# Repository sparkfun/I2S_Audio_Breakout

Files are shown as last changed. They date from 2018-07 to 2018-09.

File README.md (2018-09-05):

SparkFun I2S Audio Breakout
========================================

I2S Audio Breakout

[*I2S Audio Breakout (DEV-14809)*](https://www.sparkfun.com/products/14809)

The I2S Audio Breakout board uses the MAX98357A digital to analog converter (DAC), which converts I2S (not be confused with I2C) audio to an analog signal to drive speakers. The MAX98357A has a built in class D amplifier which can deliver up to 3.2W of power into a 4Ω load. To use this board, all you need is a speaker and a microcontroller that supports I2S. I2S is currently supported on our [SAMD21 Dev Breakout](https://www.sparkfun.com/products/13672), [SAMD21 Mini](https://www.sparkfun.com/products/13664), [ESP8266 Thing](https://www.sparkfun.com/products/13231), and [ESP32 Thing](https://www.sparkfun.com/products/13907) boards.

Repository Contents
-------------------

* **/Hardware** - Eagle design files (.brd, .sch)
* **/Production** - Production panel files (.brd)

Documentation
--------------
* **[Hookup Guide](https://learn.sparkfun.com/tutorials/i2s-audio-breakout-hookup-guide)** - Basic hookup guide for the I2S Audio Breakout.

License Information
-------------------

This product is _**open source**_! 

Please review the LICENSE.md file for license information. 

If you have any questions or concerns on licensing, please contact techsupport@sparkfun.com.

Distributed as-is; no warranty is given.

- Your friends at SparkFun.

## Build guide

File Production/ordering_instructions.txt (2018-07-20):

panel size, 222x160mm
PCB thickness, 1.6mm
number of layers, 2
soldermask color, Red
silkscreen color, White
oz copper, 1oz
finish, HASL lead free
stencils, none
pcs per panel, 70

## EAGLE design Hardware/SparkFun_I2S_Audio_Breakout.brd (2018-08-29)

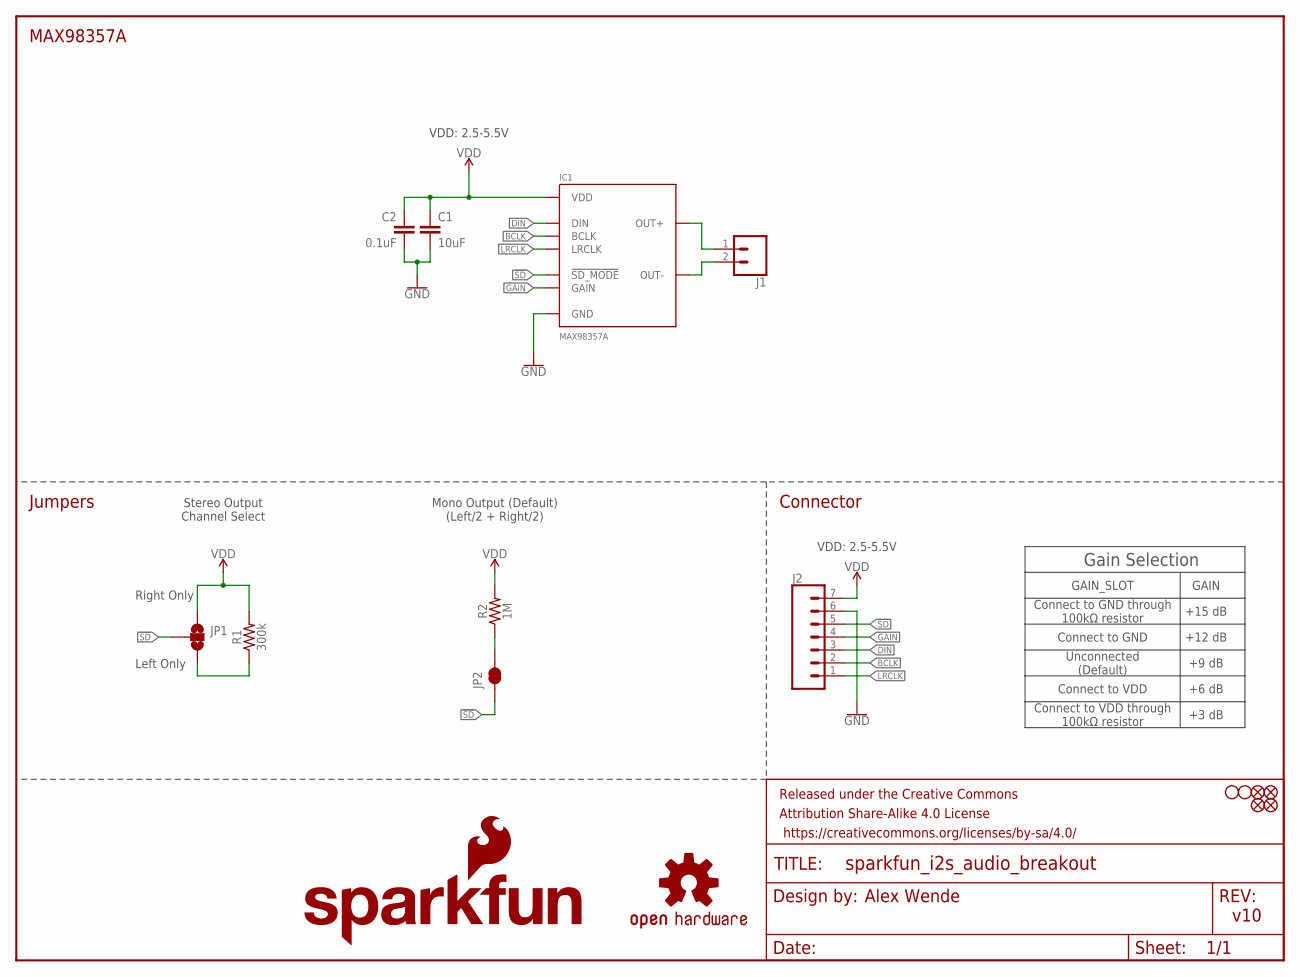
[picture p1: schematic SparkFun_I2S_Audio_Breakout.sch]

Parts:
C1: 10uF; 0805
C2: 0.1uF; 0603
FD1, FD2, FD3, FD4: FIDUCIALUFIDUCIAL; FIDUCIAL-MICRO
FRAME1: FRAME-LETTER; CREATIVE_COMMONS
H1, H2: STAND-OFF
IC1: MAX98357A; TQFN-16
J1: CONN_023.5MM-NO_SILK; SCREWTERMINAL-3.5MM-2-NS
J2: CONN_07NO_SILK; 1X07_NO_SILK
JP1: JUMPER-SMT_3_NO_NO-SILK; SMT-JUMPER_3_NO_NO-SILK
JP2: JUMPER-SMT_2_NC_TRACE_NO-SILK; SMT-JUMPER_2_NC_TRACE_NO-SILK
LOGO1: SFE_LOGO_NAME_FLAME.1_INCH; SFE_LOGO_NAME_FLAME_.1
LOGO2: OSHW-LOGOS; OSHW-LOGO-S
R1: 300k; 0603
R2: 1M; 0603

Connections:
!SD: IC1.P$4 (!SD_MODE), J2.5, JP1.2, JP2.1
BCLK: IC1.P$16 (BCLK), J2.2
DIN: IC1.P$1 (DIN), J2.3
GAIN: IC1.P$2 (GAIN), J2.4
GND: C1.2, C2.2, IC1.P$3 (GND), IC1.P$11 (GND), IC1.P$15 (GND), IC1.P$EP (GND), J2.6
LRCLK: IC1.P$14 (LRCLK), J2.1
unnamed: JP2.2, R2.1
unnamed: JP1.3, R1.1
OUT+: IC1.P$9 (OUT+), J1.1
OUT-: IC1.P$10 (OUT-), J1.2
VDD: C1.1, C2.1, IC1.P$7 (VDD), IC1.P$8 (VDD), J2.7, JP1.1, R1.2, R2.2

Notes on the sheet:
Alex Wende
v10
MAX98357A
Connector
Jumpers
Left Only
Right Only
Mono Output (Default) (Left/2 + Right/2)
Stereo Output Channel Select
Gain Selection
Connect to GND through 100kΩ resistor
Connect to GND
Unconnected (Default)
Connect to VDD
Connect to VDD through 100kΩ resistor
+15 dB
+12 dB
+9 dB
+6 dB
+3 dB
GAIN_SLOT
GAIN
VDD: 2.5-5.5V

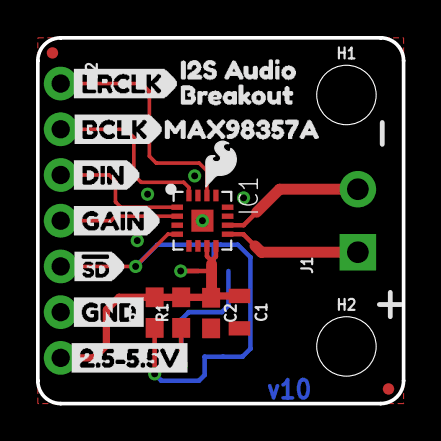
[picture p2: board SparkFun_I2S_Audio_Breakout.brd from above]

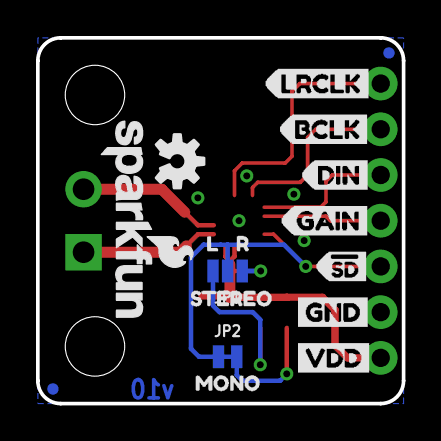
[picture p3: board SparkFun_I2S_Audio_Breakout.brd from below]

Board: 2 copper layers, 20.3 x 20.3 mm, 40 parts (17 on the bottom side), 11 nets.

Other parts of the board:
U$1: 2#5#5#5V13
U$2, U$23: GND9
U$3: #SD7
U$4: GAIN6
U$5: DIN5
U$6: BCLK4
U$7: LRCLK3
U$8: I2S_AUDIO0
U$9: BREAKOUT1
U$10: MAX98357A2
U$11: LRCLK0
U$12: BCLK1
U$13: DIN2
U$14: GAIN3
U$15: SFE_LOGO_FLAME_.1
U$16: MONO12
U$17: L10
U$18: R11
U$19: STEREO14
U$20: #SD4
U$22: VDD8

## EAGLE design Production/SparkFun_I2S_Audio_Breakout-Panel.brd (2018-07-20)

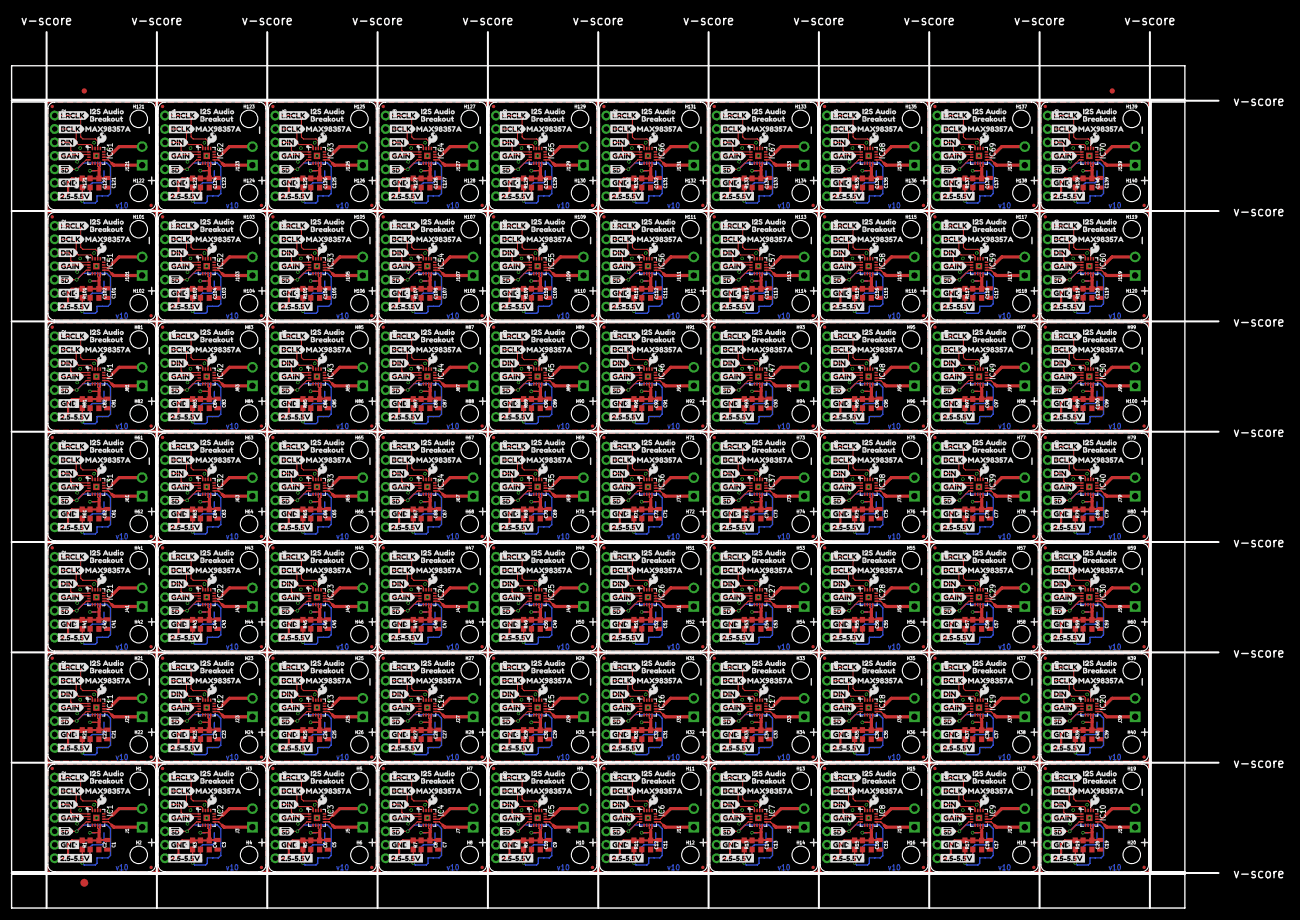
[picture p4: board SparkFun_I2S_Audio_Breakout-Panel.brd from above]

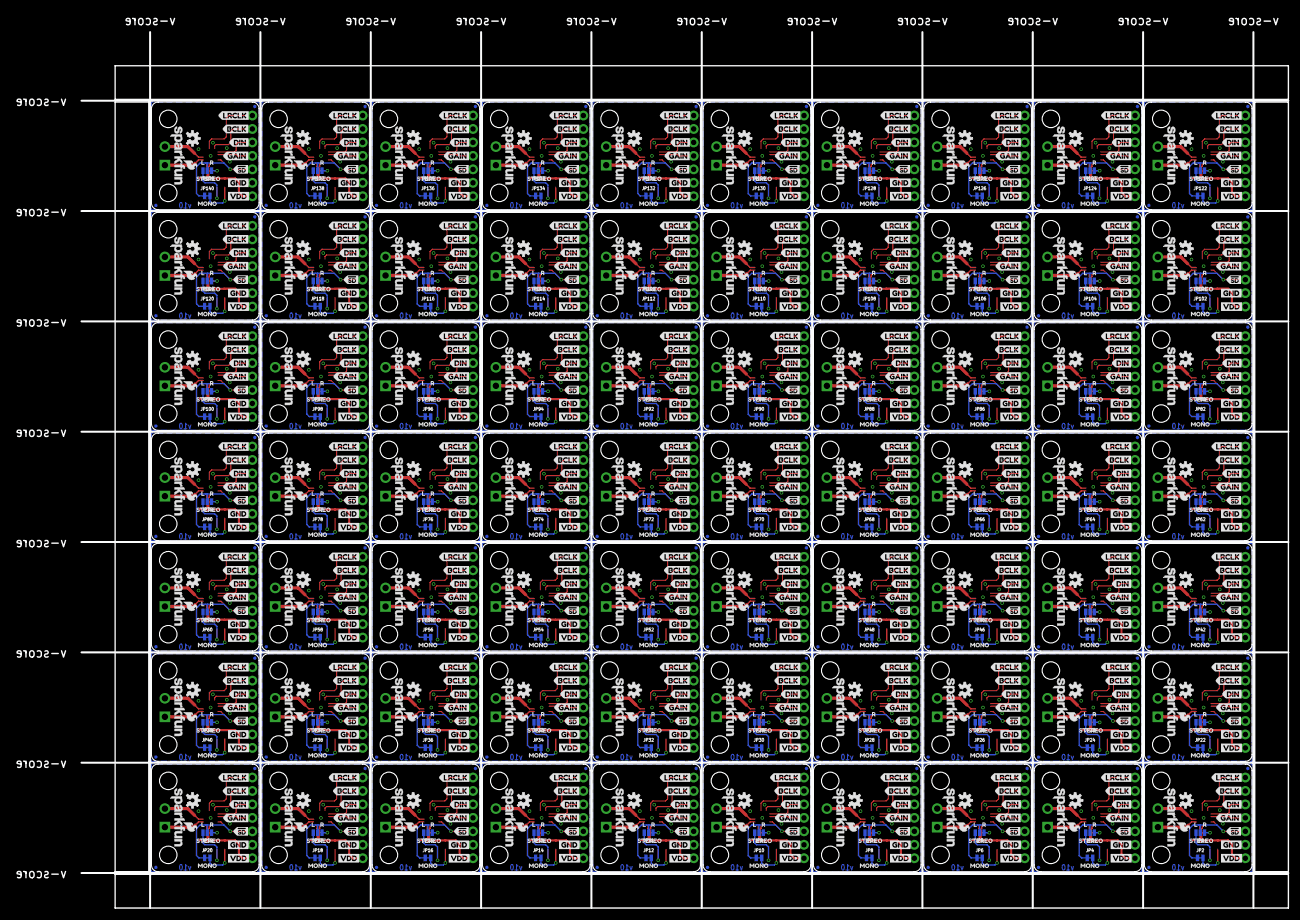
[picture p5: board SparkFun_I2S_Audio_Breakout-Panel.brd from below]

Board: 2 copper layers, 227.8 x 165.4 mm, 2733 parts (1190 on the bottom side), 770 nets.

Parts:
C1, C3, C5, C7, C9, C11, C13, C15, C17, C19, C21, C23, C25, C27, C29, C31, C33, C35, C37, C39, C41, C43, C45, C47, C49, C51, C53, C55, C57, C59, C61, C63, C65, C67, C69, C71, C73, C75, C77, C79, C81, C83, C85, C87, C89, C91, C93, C95, C97, C99, C101, C103, C105, C107, C109, C111, C113, C115, C117, C119, C121, C123, C125, C127, C129, C131, C133, C135, C137, C139: 10uF; 0805
C2, C4, C6, C8, C10, C12, C14, C16, C18, C20, C22, C24, C26, C28, C30, C32, C34, C36, C38, C40, C42, C44, C46, C48, C50, C52, C54, C56, C58, C60, C62, C64, C66, C68, C70, C72, C74, C76, C78, C80, C82, C84, C86, C88, C90, C92, C94, C96, C98, C100, C102, C104, C106, C108, C110, C112, C114, C116, C118, C120, C122, C124, C126, C128, C130, C132, C134, C136, C138, C140: 0.1uF; 0603
E$1, E$2: FIDUCIAL-1X2
E$3: FIDUCIAL-1.5X3
FD1, FD2, FD3, FD4, FD5, FD6, FD7, FD8, FD9, FD10, FD11, FD12, FD13, FD14, FD15, FD16, FD17, FD18, FD19, FD20, FD21, FD22, FD23, FD24, FD25, FD26, FD27, FD28, FD29, FD30, FD31, FD32, FD33, FD34, FD35, FD36, FD37, FD38, FD39, FD40, FD41, FD42, FD43, FD44, FD45, FD46, FD47, FD48, FD49, FD50, FD51, FD52, FD53, FD54, FD55, FD56, FD57, FD58, FD59, FD60, FD61, FD62, FD63, FD64, FD65, FD66, FD67, FD68, FD69, FD70, FD71, FD72, FD73, FD74, FD75, FD76, FD77, FD78, FD79, FD80, FD81, FD82, FD83, FD84, FD85, FD86, FD87, FD88, FD89, FD90, FD91, FD92, FD93, FD94, FD95, FD96, FD97, FD98, FD99, FD100, FD101, FD102, FD103, FD104, FD105, FD106, FD107, FD108, FD109, FD110, FD111, FD112, FD113, FD114, FD115, FD116, FD117, FD118, FD119, FD120, FD121, FD122, FD123, FD124, FD125, FD126, FD127, FD128, FD129, FD130, FD131, FD132, FD133, FD134, FD135, FD136, FD137, FD138, FD139, FD140, FD141, FD142, FD143, FD144, FD145, FD146, FD147, FD148, FD149, FD150, FD151, FD152, FD153, FD154, FD155, FD156, FD157, FD158, FD159, FD160, FD161, FD162, FD163, FD164, FD165, FD166, FD167, FD168, FD169, FD170, FD171, FD172, FD173, FD174, FD175, FD176, FD177, FD178, FD179, FD180, FD181, FD182, FD183, FD184, FD185, FD186, FD187, FD188, FD189, FD190, FD191, FD192, FD193, FD194, FD195, FD196, FD197, FD198, FD199, FD200, FD201, FD202, FD203, FD204, FD205, FD206, FD207, FD208, FD209, FD210, FD211, FD212, FD213, FD214, FD215, FD216, FD217, FD218, FD219, FD220, FD221, FD222, FD223, FD224, FD225, FD226, FD227, FD228, FD229, FD230, FD231, FD232, FD233, FD234, FD235, FD236, FD237, FD238, FD239, FD240, FD241, FD242, FD243, FD244, FD245, FD246, FD247, FD248, FD249, FD250, FD251, FD252, FD253, FD254, FD255, FD256, FD257, FD258, FD259, FD260, FD261, FD262, FD263, FD264, FD265, FD266, FD267, FD268, FD269, FD270, FD271, FD272, FD273, FD274, FD275, FD276, FD277, FD278, FD279, FD280: FIDUCIALUFIDUCIAL; FIDUCIAL-MICRO
H1, H2, H3, H4, H5, H6, H7, H8, H9, H10, H11, H12, H13, H14, H15, H16, H17, H18, H19, H20, H21, H22, H23, H24, H25, H26, H27, H28, H29, H30, H31, H32, H33, H34, H35, H36, H37, H38, H39, H40, H41, H42, H43, H44, H45, H46, H47, H48, H49, H50, H51, H52, H53, H54, H55, H56, H57, H58, H59, H60, H61, H62, H63, H64, H65, H66, H67, H68, H69, H70, H71, H72, H73, H74, H75, H76, H77, H78, H79, H80, H81, H82, H83, H84, H85, H86, H87, H88, H89, H90, H91, H92, H93, H94, H95, H96, H97, H98, H99, H100, H101, H102, H103, H104, H105, H106, H107, H108, H109, H110, H111, H112, H113, H114, H115, H116, H117, H118, H119, H120, H121, H122, H123, H124, H125, H126, H127, H128, H129, H130, H131, H132, H133, H134, H135, H136, H137, H138, H139, H140: STAND-OFF
IC1, IC2, IC3, IC4, IC5, IC6, IC7, IC8, IC9, IC10, IC11, IC12, IC13, IC14, IC15, IC16, IC17, IC18, IC19, IC20, IC21, IC22, IC23, IC24, IC25, IC26, IC27, IC28, IC29, IC30, IC31, IC32, IC33, IC34, IC35, IC36, IC37, IC38, IC39, IC40, IC41, IC42, IC43, IC44, IC45, IC46, IC47, IC48, IC49, IC50, IC51, IC52, IC53, IC54, IC55, IC56, IC57, IC58, IC59, IC60, IC61, IC62, IC63, IC64, IC65, IC66, IC67, IC68, IC69, IC70: MAX98375A; TQFN-16
J1, J3, J5, J7, J9, J11, J13, J15, J17, J19, J21, J23, J25, J27, J29, J31, J33, J35, J37, J39, J41, J43, J45, J47, J49, J51, J53, J55, J57, J59, J61, J63, J65, J67, J69, J71, J73, J75, J77, J79, J81, J83, J85, J87, J89, J91, J93, J95, J97, J99, J101, J103, J105, J107, J109, J111, J113, J115, J117, J119, J121, J123, J125, J127, J129, J131, J133, J135, J137, J139: SCREWTERMINAL-3.5MM-2-NS
J2, J4, J6, J8, J10, J12, J14, J16, J18, J20, J22, J24, J26, J28, J30, J32, J34, J36, J38, J40, J42, J44, J46, J48, J50, J52, J54, J56, J58, J60, J62, J64, J66, J68, J70, J72, J74, J76, J78, J80, J82, J84, J86, J88, J90, J92, J94, J96, J98, J100, J102, J104, J106, J108, J110, J112, J114, J116, J118, J120, J122, J124, J126, J128, J130, J132, J134, J136, J138, J140: 1X07_NO_SILK
JP1, JP3, JP5, JP7, JP9, JP11, JP13, JP15, JP17, JP19, JP21, JP23, JP25, JP27, JP29, JP31, JP33, JP35, JP37, JP39, JP41, JP43, JP45, JP47, JP49, JP51, JP53, JP55, JP57, JP59, JP61, JP63, JP65, JP67, JP69, JP71, JP73, JP75, JP77, JP79, JP81, JP83, JP85, JP87, JP89, JP91, JP93, JP95, JP97, JP99, JP101, JP103, JP105, JP107, JP109, JP111, JP113, JP115, JP117, JP119, JP121, JP123, JP125, JP127, JP129, JP131, JP133, JP135, JP137, JP139: SMT-JUMPER_3_NO_NO-SILK
JP2, JP4, JP6, JP8, JP10, JP12, JP14, JP16, JP18, JP20, JP22, JP24, JP26, JP28, JP30, JP32, JP34, JP36, JP38, JP40, JP42, JP44, JP46, JP48, JP50, JP52, JP54, JP56, JP58, JP60, JP62, JP64, JP66, JP68, JP70, JP72, JP74, JP76, JP78, JP80, JP82, JP84, JP86, JP88, JP90, JP92, JP94, JP96, JP98, JP100, JP102, JP104, JP106, JP108, JP110, JP112, JP114, JP116, JP118, JP120, JP122, JP124, JP126, JP128, JP130, JP132, JP134, JP136, JP138, JP140: SMT-JUMPER_2_NC_TRACE_NO-SILK
LOGO1, LOGO3, LOGO5, LOGO7, LOGO9, LOGO11, LOGO13, LOGO15, LOGO17, LOGO19, LOGO21, LOGO23, LOGO25, LOGO27, LOGO29, LOGO31, LOGO33, LOGO35, LOGO37, LOGO39, LOGO41, LOGO43, LOGO45, LOGO47, LOGO49, LOGO51, LOGO53, LOGO55, LOGO57, LOGO59, LOGO61, LOGO63, LOGO65, LOGO67, LOGO69, LOGO71, LOGO73, LOGO75, LOGO77, LOGO79, LOGO81, LOGO83, LOGO85, LOGO87, LOGO89, LOGO91, LOGO93, LOGO95, LOGO97, LOGO99, LOGO101, LOGO103, LOGO105, LOGO107, LOGO109, LOGO111, LOGO113, LOGO115, LOGO117, LOGO119, LOGO121, LOGO123, LOGO125, LOGO127, LOGO129, LOGO131, LOGO133, LOGO135, LOGO137, LOGO139: SFE_LOGO_NAME_FLAME.1_INCH; SFE_LOGO_NAME_FLAME_.1
LOGO2, LOGO4, LOGO6, LOGO8, LOGO10, LOGO12, LOGO14, LOGO16, LOGO18, LOGO20, LOGO22, LOGO24, LOGO26, LOGO28, LOGO30, LOGO32, LOGO34, LOGO36, LOGO38, LOGO40, LOGO42, LOGO44, LOGO46, LOGO48, LOGO50, LOGO52, LOGO54, LOGO56, LOGO58, LOGO60, LOGO62, LOGO64, LOGO66, LOGO68, LOGO70, LOGO72, LOGO74, LOGO76, LOGO78, LOGO80, LOGO82, LOGO84, LOGO86, LOGO88, LOGO90, LOGO92, LOGO94, LOGO96, LOGO98, LOGO100, LOGO102, LOGO104, LOGO106, LOGO108, LOGO110, LOGO112, LOGO114, LOGO116, LOGO118, LOGO120, LOGO122, LOGO124, LOGO126, LOGO128, LOGO130, LOGO132, LOGO134, LOGO136, LOGO138, LOGO140: OSHW-LOGOS; OSHW-LOGO-S
R1, R3, R5, R7, R9, R11, R13, R15, R17, R19, R21, R23, R25, R27, R29, R31, R33, R35, R37, R39, R41, R43, R45, R47, R49, R51, R53, R55, R57, R59, R61, R63, R65, R67, R69, R71, R73, R75, R77, R79, R81, R83, R85, R87, R89, R91, R93, R95, R97, R99, R101, R103, R105, R107, R109, R111, R113, R115, R117, R119, R121, R123, R125, R127, R129, R131, R133, R135, R137, R139: 300k; 0603
R2, R4, R6, R8, R10, R12, R14, R16, R18, R20, R22, R24, R26, R28, R30, R32, R34, R36, R38, R40, R42, R44, R46, R48, R50, R52, R54, R56, R58, R60, R62, R64, R66, R68, R70, R72, R74, R76, R78, R80, R82, R84, R86, R88, R90, R92, R94, R96, R98, R100, R102, R104, R106, R108, R110, R112, R114, R116, R118, R120, R122, R124, R126, R128, R130, R132, R134, R136, R138, R140: 1M; 0603
U$1, U$24, U$46, U$68, U$90, U$112, U$134, U$156, U$178, U$200, U$222, U$244, U$266, U$288, U$310, U$332, U$354, U$376, U$398, U$420, U$442, U$464, U$486, U$508, U$530, U$552, U$574, U$596, U$618, U$640, U$662, U$684, U$706, U$728, U$750, U$772, U$794, U$816, U$838, U$860, U$882, U$904, U$926, U$948, U$970, U$992, U$1014, U$1036, U$1058, U$1080, U$1102, U$1124, U$1146, U$1168, U$1190, U$1212, U$1234, U$1256, U$1278, U$1300, U$1322, U$1344, U$1366, U$1388, U$1410, U$1432, U$1454, U$1476, U$1498, U$1520: 2#5#5#5V13
U$2, U$23, U$25, U$39, U$47, U$61, U$69, U$83, U$91, U$105, U$113, U$127, U$135, U$149, U$157, U$171, U$179, U$193, U$201, U$215, U$223, U$237, U$245, U$259, U$267, U$281, U$289, U$303, U$311, U$325, U$333, U$347, U$355, U$369, U$377, U$391, U$399, U$413, U$421, U$435, U$443, U$457, U$465, U$479, U$487, U$501, U$509, U$523, U$531, U$545, U$553, U$567, U$575, U$589, U$597, U$611, U$619, U$633, U$641, U$655, U$663, U$677, U$685, U$699, U$707, U$721, U$729, U$743, U$751, U$765, U$773, U$787, U$795, U$809, U$817, U$831, U$839, U$853, U$861, U$875, U$883, U$897, U$905, U$919, U$927, U$941, U$949, U$963, U$971, U$985, U$993, U$1007, U$1015, U$1029, U$1037, U$1051, U$1059, U$1073, U$1081, U$1095, U$1103, U$1117, U$1125, U$1139, U$1147, U$1161, U$1169, U$1183, U$1191, U$1205, U$1213, U$1227, U$1235, U$1249, U$1257, U$1271, U$1279, U$1293, U$1301, U$1315, U$1323, U$1337, U$1345, U$1359, U$1367, U$1381, U$1389, U$1403, U$1411, U$1425, U$1433, U$1447, U$1455, U$1469, U$1477, U$1491, U$1499, U$1513, U$1521, U$1535: GND9
U$3, U$26, U$48, U$70, U$92, U$114, U$136, U$158, U$180, U$202, U$224, U$246, U$268, U$290, U$312, U$334, U$356, U$378, U$400, U$422, U$444, U$466, U$488, U$510, U$532, U$554, U$576, U$598, U$620, U$642, U$664, U$686, U$708, U$730, U$752, U$774, U$796, U$818, U$840, U$862, U$884, U$906, U$928, U$950, U$972, U$994, U$1016, U$1038, U$1060, U$1082, U$1104, U$1126, U$1148, U$1170, U$1192, U$1214, U$1236, U$1258, U$1280, U$1302, U$1324, U$1346, U$1368, U$1390, U$1412, U$1434, U$1456, U$1478, U$1500, U$1522: #SD7
U$4, U$27, U$49, U$71, U$93, U$115, U$137, U$159, U$181, U$203, U$225, U$247, U$269, U$291, U$313, U$335, U$357, U$379, U$401, U$423, U$445, U$467, U$489, U$511, U$533, U$555, U$577, U$599, U$621, U$643, U$665, U$687, U$709, U$731, U$753, U$775, U$797, U$819, U$841, U$863, U$885, U$907, U$929, U$951, U$973, U$995, U$1017, U$1039, U$1061, U$1083, U$1105, U$1127, U$1149, U$1171, U$1193, U$1215, U$1237, U$1259, U$1281, U$1303, U$1325, U$1347, U$1369, U$1391, U$1413, U$1435, U$1457, U$1479, U$1501, U$1523: GAIN6
U$5, U$28, U$50, U$72, U$94, U$116, U$138, U$160, U$182, U$204, U$226, U$248, U$270, U$292, U$314, U$336, U$358, U$380, U$402, U$424, U$446, U$468, U$490, U$512, U$534, U$556, U$578, U$600, U$622, U$644, U$666, U$688, U$710, U$732, U$754, U$776, U$798, U$820, U$842, U$864, U$886, U$908, U$930, U$952, U$974, U$996, U$1018, U$1040, U$1062, U$1084, U$1106, U$1128, U$1150, U$1172, U$1194, U$1216, U$1238, U$1260, U$1282, U$1304, U$1326, U$1348, U$1370, U$1392, U$1414, U$1436, U$1458, U$1480, U$1502, U$1524: DIN5
U$6, U$29, U$51, U$73, U$95, U$117, U$139, U$161, U$183, U$205, U$227, U$249, U$271, U$293, U$315, U$337, U$359, U$381, U$403, U$425, U$447, U$469, U$491, U$513, U$535, U$557, U$579, U$601, U$623, U$645, U$667, U$689, U$711, U$733, U$755, U$777, U$799, U$821, U$843, U$865, U$887, U$909, U$931, U$953, U$975, U$997, U$1019, U$1041, U$1063, U$1085, U$1107, U$1129, U$1151, U$1173, U$1195, U$1217, U$1239, U$1261, U$1283, U$1305, U$1327, U$1349, U$1371, U$1393, U$1415, U$1437, U$1459, U$1481, U$1503, U$1525: BCLK4
U$7, U$30, U$52, U$74, U$96, U$118, U$140, U$162, U$184, U$206, U$228, U$250, U$272, U$294, U$316, U$338, U$360, U$382, U$404, U$426, U$448, U$470, U$492, U$514, U$536, U$558, U$580, U$602, U$624, U$646, U$668, U$690, U$712, U$734, U$756, U$778, U$800, U$822, U$844, U$866, U$888, U$910, U$932, U$954, U$976, U$998, U$1020, U$1042, U$1064, U$1086, U$1108, U$1130, U$1152, U$1174, U$1196, U$1218, U$1240, U$1262, U$1284, U$1306, U$1328, U$1350, U$1372, U$1394, U$1416, U$1438, U$1460, U$1482, U$1504, U$1526: LRCLK3
U$8, U$31, U$53, U$75, U$97, U$119, U$141, U$163, U$185, U$207, U$229, U$251, U$273, U$295, U$317, U$339, U$361, U$383, U$405, U$427, U$449, U$471, U$493, U$515, U$537, U$559, U$581, U$603, U$625, U$647, U$669, U$691, U$713, U$735, U$757, U$779, U$801, U$823, U$845, U$867, U$889, U$911, U$933, U$955, U$977, U$999, U$1021, U$1043, U$1065, U$1087, U$1109, U$1131, U$1153, U$1175, U$1197, U$1219, U$1241, U$1263, U$1285, U$1307, U$1329, U$1351, U$1373, U$1395, U$1417, U$1439, U$1461, U$1483, U$1505, U$1527: I2S_AUDIO0
U$9, U$32, U$54, U$76, U$98, U$120, U$142, U$164, U$186, U$208, U$230, U$252, U$274, U$296, U$318, U$340, U$362, U$384, U$406, U$428, U$450, U$472, U$494, U$516, U$538, U$560, U$582, U$604, U$626, U$648, U$670, U$692, U$714, U$736, U$758, U$780, U$802, U$824, U$846, U$868, U$890, U$912, U$934, U$956, U$978, U$1000, U$1022, U$1044, U$1066, U$1088, U$1110, U$1132, U$1154, U$1176, U$1198, U$1220, U$1242, U$1264, U$1286, U$1308, U$1330, U$1352, U$1374, U$1396, U$1418, U$1440, U$1462, U$1484, U$1506, U$1528: BREAKOUT1
U$10, U$33, U$55, U$77, U$99, U$121, U$143, U$165, U$187, U$209, U$231, U$253, U$275, U$297, U$319, U$341, U$363, U$385, U$407, U$429, U$451, U$473, U$495, U$517, U$539, U$561, U$583, U$605, U$627, U$649, U$671, U$693, U$715, U$737, U$759, U$781, U$803, U$825, U$847, U$869, U$891, U$913, U$935, U$957, U$979, U$1001, U$1023, U$1045, U$1067, U$1089, U$1111, U$1133, U$1155, U$1177, U$1199, U$1221, U$1243, U$1265, U$1287, U$1309, U$1331, U$1353, U$1375, U$1397, U$1419, U$1441, U$1463, U$1485, U$1507, U$1529: MAX98357A2
U$11, U$40, U$62, U$84, U$106, U$128, U$150, U$172, U$194, U$216, U$238, U$260, U$282, U$304, U$326, U$348, U$370, U$392, U$414, U$436, U$458, U$480, U$502, U$524, U$546, U$568, U$590, U$612, U$634, U$656, U$678, U$700, U$722, U$744, U$766, U$788, U$810, U$832, U$854, U$876, U$898, U$920, U$942, U$964, U$986, U$1008, U$1030, U$1052, U$1074, U$1096, U$1118, U$1140, U$1162, U$1184, U$1206, U$1228, U$1250, U$1272, U$1294, U$1316, U$1338, U$1360, U$1382, U$1404, U$1426, U$1448, U$1470, U$1492, U$1514, U$1536: LRCLK0
U$12, U$41, U$63, U$85, U$107, U$129, U$151, U$173, U$195, U$217, U$239, U$261, U$283, U$305, U$327, U$349, U$371, U$393, U$415, U$437, U$459, U$481, U$503, U$525, U$547, U$569, U$591, U$613, U$635, U$657, U$679, U$701, U$723, U$745, U$767, U$789, U$811, U$833, U$855, U$877, U$899, U$921, U$943, U$965, U$987, U$1009, U$1031, U$1053, U$1075, U$1097, U$1119, U$1141, U$1163, U$1185, U$1207, U$1229, U$1251, U$1273, U$1295, U$1317, U$1339, U$1361, U$1383, U$1405, U$1427, U$1449, U$1471, U$1493, U$1515, U$1537: BCLK1
U$13, U$42, U$64, U$86, U$108, U$130, U$152, U$174, U$196, U$218, U$240, U$262, U$284, U$306, U$328, U$350, U$372, U$394, U$416, U$438, U$460, U$482, U$504, U$526, U$548, U$570, U$592, U$614, U$636, U$658, U$680, U$702, U$724, U$746, U$768, U$790, U$812, U$834, U$856, U$878, U$900, U$922, U$944, U$966, U$988, U$1010, U$1032, U$1054, U$1076, U$1098, U$1120, U$1142, U$1164, U$1186, U$1208, U$1230, U$1252, U$1274, U$1296, U$1318, U$1340, U$1362, U$1384, U$1406, U$1428, U$1450, U$1472, U$1494, U$1516, U$1538: DIN2
U$14, U$43, U$65, U$87, U$109, U$131, U$153, U$175, U$197, U$219, U$241, U$263, U$285, U$307, U$329, U$351, U$373, U$395, U$417, U$439, U$461, U$483, U$505, U$527, U$549, U$571, U$593, U$615, U$637, U$659, U$681, U$703, U$725, U$747, U$769, U$791, U$813, U$835, U$857, U$879, U$901, U$923, U$945, U$967, U$989, U$1011, U$1033, U$1055, U$1077, U$1099, U$1121, U$1143, U$1165, U$1187, U$1209, U$1231, U$1253, U$1275, U$1297, U$1319, U$1341, U$1363, U$1385, U$1407, U$1429, U$1451, U$1473, U$1495, U$1517, U$1539: GAIN3
U$15, U$21, U$45, U$67, U$89, U$111, U$133, U$155, U$177, U$199, U$221, U$243, U$265, U$287, U$309, U$331, U$353, U$375, U$397, U$419, U$441, U$463, U$485, U$507, U$529, U$551, U$573, U$595, U$617, U$639, U$661, U$683, U$705, U$727, U$749, U$771, U$793, U$815, U$837, U$859, U$881, U$903, U$925, U$947, U$969, U$991, U$1013, U$1035, U$1057, U$1079, U$1101, U$1123, U$1145, U$1167, U$1189, U$1211, U$1233, U$1255, U$1277, U$1299, U$1321, U$1343, U$1365, U$1387, U$1409, U$1431, U$1453, U$1475, U$1497, U$1519: SFE_LOGO_FLAME_.1
U$16, U$35, U$57, U$79, U$101, U$123, U$145, U$167, U$189, U$211, U$233, U$255, U$277, U$299, U$321, U$343, U$365, U$387, U$409, U$431, U$453, U$475, U$497, U$519, U$541, U$563, U$585, U$607, U$629, U$651, U$673, U$695, U$717, U$739, U$761, U$783, U$805, U$827, U$849, U$871, U$893, U$915, U$937, U$959, U$981, U$1003, U$1025, U$1047, U$1069, U$1091, U$1113, U$1135, U$1157, U$1179, U$1201, U$1223, U$1245, U$1267, U$1289, U$1311, U$1333, U$1355, U$1377, U$1399, U$1421, U$1443, U$1465, U$1487, U$1509, U$1531: MONO12
U$17, U$37, U$59, U$81, U$103, U$125, U$147, U$169, U$191, U$213, U$235, U$257, U$279, U$301, U$323, U$345, U$367, U$389, U$411, U$433, U$455, U$477, U$499, U$521, U$543, U$565, U$587, U$609, U$631, U$653, U$675, U$697, U$719, U$741, U$763, U$785, U$807, U$829, U$851, U$873, U$895, U$917, U$939, U$961, U$983, U$1005, U$1027, U$1049, U$1071, U$1093, U$1115, U$1137, U$1159, U$1181, U$1203, U$1225, U$1247, U$1269, U$1291, U$1313, U$1335, U$1357, U$1379, U$1401, U$1423, U$1445, U$1467, U$1489, U$1511, U$1533: L10
U$18, U$38, U$60, U$82, U$104, U$126, U$148, U$170, U$192, U$214, U$236, U$258, U$280, U$302, U$324, U$346, U$368, U$390, U$412, U$434, U$456, U$478, U$500, U$522, U$544, U$566, U$588, U$610, U$632, U$654, U$676, U$698, U$720, U$742, U$764, U$786, U$808, U$830, U$852, U$874, U$896, U$918, U$940, U$962, U$984, U$1006, U$1028, U$1050, U$1072, U$1094, U$1116, U$1138, U$1160, U$1182, U$1204, U$1226, U$1248, U$1270, U$1292, U$1314, U$1336, U$1358, U$1380, U$1402, U$1424, U$1446, U$1468, U$1490, U$1512, U$1534: R11
U$19, U$36, U$58, U$80, U$102, U$124, U$146, U$168, U$190, U$212, U$234, U$256, U$278, U$300, U$322, U$344, U$366, U$388, U$410, U$432, U$454, U$476, U$498, U$520, U$542, U$564, U$586, U$608, U$630, U$652, U$674, U$696, U$718, U$740, U$762, U$784, U$806, U$828, U$850, U$872, U$894, U$916, U$938, U$960, U$982, U$1004, U$1026, U$1048, U$1070, U$1092, U$1114, U$1136, U$1158, U$1180, U$1202, U$1224, U$1246, U$1268, U$1290, U$1312, U$1334, U$1356, U$1378, U$1400, U$1422, U$1444, U$1466, U$1488, U$1510, U$1532: STEREO14
U$20, U$44, U$66, U$88, U$110, U$132, U$154, U$176, U$198, U$220, U$242, U$264, U$286, U$308, U$330, U$352, U$374, U$396, U$418, U$440, U$462, U$484, U$506, U$528, U$550, U$572, U$594, U$616, U$638, U$660, U$682, U$704, U$726, U$748, U$770, U$792, U$814, U$836, U$858, U$880, U$902, U$924, U$946, U$968, U$990, U$1012, U$1034, U$1056, U$1078, U$1100, U$1122, U$1144, U$1166, U$1188, U$1210, U$1232, U$1254, U$1276, U$1298, U$1320, U$1342, U$1364, U$1386, U$1408, U$1430, U$1452, U$1474, U$1496, U$1518, U$1540: #SD4
U$22, U$34, U$56, U$78, U$100, U$122, U$144, U$166, U$188, U$210, U$232, U$254, U$276, U$298, U$320, U$342, U$364, U$386, U$408, U$430, U$452, U$474, U$496, U$518, U$540, U$562, U$584, U$606, U$628, U$650, U$672, U$694, U$716, U$738, U$760, U$782, U$804, U$826, U$848, U$870, U$892, U$914, U$936, U$958, U$980, U$1002, U$1024, U$1046, U$1068, U$1090, U$1112, U$1134, U$1156, U$1178, U$1200, U$1222, U$1244, U$1266, U$1288, U$1310, U$1332, U$1354, U$1376, U$1398, U$1420, U$1442, U$1464, U$1486, U$1508, U$1530: VDD8

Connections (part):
!SD: IC1.P$4, J2.5, JP1.2, JP2.1
!SD1: IC2.P$4, J4.5, JP3.2, JP4.1
!SD2: IC3.P$4, J6.5, JP5.2, JP6.1
!SD3: IC4.P$4, J8.5, JP7.2, JP8.1
!SD4: IC5.P$4, J10.5, JP9.2, JP10.1
!SD5: IC6.P$4, J12.5, JP11.2, JP12.1
!SD6: IC7.P$4, J14.5, JP13.2, JP14.1
!SD7: IC8.P$4, J16.5, JP15.2, JP16.1
!SD8: IC9.P$4, J18.5, JP17.2, JP18.1
!SD9: IC10.P$4, J20.5, JP19.2, JP20.1
!SD10: IC11.P$4, J22.5, JP21.2, JP22.1
!SD11: IC12.P$4, J24.5, JP23.2, JP24.1
!SD12: IC13.P$4, J26.5, JP25.2, JP26.1
!SD13: IC14.P$4, J28.5, JP27.2, JP28.1
!SD14: IC15.P$4, J30.5, JP29.2, JP30.1
!SD15: IC16.P$4, J32.5, JP31.2, JP32.1
!SD16: IC17.P$4, J34.5, JP33.2, JP34.1
!SD17: IC18.P$4, J36.5, JP35.2, JP36.1
!SD18: IC19.P$4, J38.5, JP37.2, JP38.1
!SD19: IC20.P$4, J40.5, JP39.2, JP40.1
!SD20: IC21.P$4, J42.5, JP41.2, JP42.1
!SD21: IC22.P$4, J44.5, JP43.2, JP44.1
!SD22: IC23.P$4, J46.5, JP45.2, JP46.1
!SD23: IC24.P$4, J48.5, JP47.2, JP48.1
!SD24: IC25.P$4, J50.5, JP49.2, JP50.1
!SD25: IC26.P$4, J52.5, JP51.2, JP52.1
!SD26: IC27.P$4, J54.5, JP53.2, JP54.1
!SD27: IC28.P$4, J56.5, JP55.2, JP56.1
!SD28: IC29.P$4, J58.5, JP57.2, JP58.1
!SD29: IC30.P$4, J60.5, JP59.2, JP60.1
!SD30: IC31.P$4, J62.5, JP61.2, JP62.1
!SD31: IC32.P$4, J64.5, JP63.2, JP64.1
!SD32: IC33.P$4, J66.5, JP65.2, JP66.1
!SD33: IC34.P$4, J68.5, JP67.2, JP68.1
!SD34: IC35.P$4, J70.5, JP69.2, JP70.1
!SD35: IC36.P$4, J72.5, JP71.2, JP72.1
!SD36: IC37.P$4, J74.5, JP73.2, JP74.1
!SD37: IC38.P$4, J76.5, JP75.2, JP76.1
!SD38: IC39.P$4, J78.5, JP77.2, JP78.1
!SD39: IC40.P$4, J80.5, JP79.2, JP80.1
!SD40: IC41.P$4, J82.5, JP81.2, JP82.1
!SD41: IC42.P$4, J84.5, JP83.2, JP84.1
!SD42: IC43.P$4, J86.5, JP85.2, JP86.1
!SD43: IC44.P$4, J88.5, JP87.2, JP88.1
!SD44: IC45.P$4, J90.5, JP89.2, JP90.1
!SD45: IC46.P$4, J92.5, JP91.2, JP92.1
!SD46: IC47.P$4, J94.5, JP93.2, JP94.1
!SD47: IC48.P$4, J96.5, JP95.2, JP96.1
!SD48: IC49.P$4, J98.5, JP97.2, JP98.1
!SD49: IC50.P$4, J100.5, JP99.2, JP100.1
!SD50: IC51.P$4, J102.5, JP101.2, JP102.1
!SD51: IC52.P$4, J104.5, JP103.2, JP104.1
!SD52: IC53.P$4, J106.5, JP105.2, JP106.1
!SD53: IC54.P$4, J108.5, JP107.2, JP108.1
!SD54: IC55.P$4, J110.5, JP109.2, JP110.1
!SD55: IC56.P$4, J112.5, JP111.2, JP112.1
!SD56: IC57.P$4, J114.5, JP113.2, JP114.1
!SD57: IC58.P$4, J116.5, JP115.2, JP116.1
!SD58: IC59.P$4, J118.5, JP117.2, JP118.1
!SD59: IC60.P$4, J120.5, JP119.2, JP120.1
!SD60: IC61.P$4, J122.5, JP121.2, JP122.1
!SD61: IC62.P$4, J124.5, JP123.2, JP124.1
!SD62: IC63.P$4, J126.5, JP125.2, JP126.1
!SD63: IC64.P$4, J128.5, JP127.2, JP128.1
!SD64: IC65.P$4, J130.5, JP129.2, JP130.1
!SD65: IC66.P$4, J132.5, JP131.2, JP132.1
!SD66: IC67.P$4, J134.5, JP133.2, JP134.1
!SD67: IC68.P$4, J136.5, JP135.2, JP136.1
!SD68: IC69.P$4, J138.5, JP137.2, JP138.1
!SD69: IC70.P$4, J140.5, JP139.2, JP140.1
BCLK: IC1.P$16, J2.2
BCLK1: IC2.P$16, J4.2
BCLK2: IC3.P$16, J6.2
BCLK3: IC4.P$16, J8.2
BCLK4: IC5.P$16, J10.2
BCLK5: IC6.P$16, J12.2
BCLK6: IC7.P$16, J14.2
BCLK7: IC8.P$16, J16.2
BCLK8: IC9.P$16, J18.2
BCLK9: IC10.P$16, J20.2
BCLK10: IC11.P$16, J22.2
BCLK11: IC12.P$16, J24.2
BCLK12: IC13.P$16, J26.2
BCLK13: IC14.P$16, J28.2
BCLK14: IC15.P$16, J30.2
BCLK15: IC16.P$16, J32.2
BCLK16: IC17.P$16, J34.2
BCLK17: IC18.P$16, J36.2
BCLK18: IC19.P$16, J38.2
BCLK19: IC20.P$16, J40.2
BCLK20: IC21.P$16, J42.2
BCLK21: IC22.P$16, J44.2
BCLK22: IC23.P$16, J46.2
BCLK23: IC24.P$16, J48.2
BCLK24: IC25.P$16, J50.2
BCLK25: IC26.P$16, J52.2
BCLK26: IC27.P$16, J54.2
BCLK27: IC28.P$16, J56.2
BCLK28: IC29.P$16, J58.2
BCLK29: IC30.P$16, J60.2
BCLK30: IC31.P$16, J62.2
BCLK31: IC32.P$16, J64.2
BCLK32: IC33.P$16, J66.2
BCLK33: IC34.P$16, J68.2
BCLK34: IC35.P$16, J70.2
BCLK35: IC36.P$16, J72.2
BCLK36: IC37.P$16, J74.2
BCLK37: IC38.P$16, J76.2
BCLK38: IC39.P$16, J78.2
BCLK39: IC40.P$16, J80.2
BCLK40: IC41.P$16, J82.2
BCLK41: IC42.P$16, J84.2
BCLK42: IC43.P$16, J86.2
BCLK43: IC44.P$16, J88.2
BCLK44: IC45.P$16, J90.2
BCLK45: IC46.P$16, J92.2
BCLK46: IC47.P$16, J94.2
BCLK47: IC48.P$16, J96.2
BCLK48: IC49.P$16, J98.2
BCLK49: IC50.P$16, J100.2
BCLK50: IC51.P$16, J102.2
BCLK51: IC52.P$16, J104.2
BCLK52: IC53.P$16, J106.2
BCLK53: IC54.P$16, J108.2
BCLK54: IC55.P$16, J110.2
BCLK55: IC56.P$16, J112.2
BCLK56: IC57.P$16, J114.2
BCLK57: IC58.P$16, J116.2
BCLK58: IC59.P$16, J118.2
BCLK59: IC60.P$16, J120.2
BCLK60: IC61.P$16, J122.2
BCLK61: IC62.P$16, J124.2
BCLK62: IC63.P$16, J126.2
BCLK63: IC64.P$16, J128.2
BCLK64: IC65.P$16, J130.2
BCLK65: IC66.P$16, J132.2
BCLK66: IC67.P$16, J134.2
BCLK67: IC68.P$16, J136.2
BCLK68: IC69.P$16, J138.2
BCLK69: IC70.P$16, J140.2
DIN: IC1.P$1, J2.3
DIN1: IC2.P$1, J4.3
DIN2: IC3.P$1, J6.3
DIN3: IC4.P$1, J8.3
DIN4: IC5.P$1, J10.3
DIN5: IC6.P$1, J12.3
DIN6: IC7.P$1, J14.3
DIN7: IC8.P$1, J16.3
DIN8: IC9.P$1, J18.3
DIN9: IC10.P$1, J20.3
DIN10: IC11.P$1, J22.3
DIN11: IC12.P$1, J24.3
DIN12: IC13.P$1, J26.3
DIN13: IC14.P$1, J28.3
DIN14: IC15.P$1, J30.3
DIN15: IC16.P$1, J32.3
DIN16: IC17.P$1, J34.3
DIN17: IC18.P$1, J36.3
DIN18: IC19.P$1, J38.3
DIN19: IC20.P$1, J40.3
DIN20: IC21.P$1, J42.3
DIN21: IC22.P$1, J44.3
DIN22: IC23.P$1, J46.3
DIN23: IC24.P$1, J48.3
DIN24: IC25.P$1, J50.3
DIN25: IC26.P$1, J52.3
DIN26: IC27.P$1, J54.3
DIN27: IC28.P$1, J56.3
DIN28: IC29.P$1, J58.3
DIN29: IC30.P$1, J60.3
DIN30: IC31.P$1, J62.3
DIN31: IC32.P$1, J64.3
DIN32: IC33.P$1, J66.3
DIN33: IC34.P$1, J68.3
DIN34: IC35.P$1, J70.3
DIN35: IC36.P$1, J72.3
DIN36: IC37.P$1, J74.3
DIN37: IC38.P$1, J76.3
DIN38: IC39.P$1, J78.3
DIN39: IC40.P$1, J80.3
DIN40: IC41.P$1, J82.3
DIN41: IC42.P$1, J84.3
DIN42: IC43.P$1, J86.3
DIN43: IC44.P$1, J88.3
DIN44: IC45.P$1, J90.3
DIN45: IC46.P$1, J92.3
DIN46: IC47.P$1, J94.3
DIN47: IC48.P$1, J96.3
DIN48: IC49.P$1, J98.3
DIN49: IC50.P$1, J100.3
DIN50: IC51.P$1, J102.3
DIN51: IC52.P$1, J104.3
DIN52: IC53.P$1, J106.3
DIN53: IC54.P$1, J108.3
DIN54: IC55.P$1, J110.3
DIN55: IC56.P$1, J112.3
DIN56: IC57.P$1, J114.3
DIN57: IC58.P$1, J116.3
DIN58: IC59.P$1, J118.3
DIN59: IC60.P$1, J120.3
DIN60: IC61.P$1, J122.3
DIN61: IC62.P$1, J124.3
DIN62: IC63.P$1, J126.3
DIN63: IC64.P$1, J128.3
DIN64: IC65.P$1, J130.3
DIN65: IC66.P$1, J132.3
DIN66: IC67.P$1, J134.3
DIN67: IC68.P$1, J136.3
DIN68: IC69.P$1, J138.3
DIN69: IC70.P$1, J140.3
GAIN: IC1.P$2, J2.4
GAIN1: IC2.P$2, J4.4
GAIN2: IC3.P$2, J6.4
GAIN3: IC4.P$2, J8.4
GAIN4: IC5.P$2, J10.4
GAIN5: IC6.P$2, J12.4
GAIN6: IC7.P$2, J14.4
GAIN7: IC8.P$2, J16.4
GAIN8: IC9.P$2, J18.4
GAIN9: IC10.P$2, J20.4
GAIN10: IC11.P$2, J22.4
GAIN11: IC12.P$2, J24.4
GAIN12: IC13.P$2, J26.4
GAIN13: IC14.P$2, J28.4
GAIN14: IC15.P$2, J30.4
GAIN15: IC16.P$2, J32.4
GAIN16: IC17.P$2, J34.4
GAIN17: IC18.P$2, J36.4
GAIN18: IC19.P$2, J38.4
GAIN19: IC20.P$2, J40.4
GAIN20: IC21.P$2, J42.4
GAIN21: IC22.P$2, J44.4
GAIN22: IC23.P$2, J46.4
GAIN23: IC24.P$2, J48.4
GAIN24: IC25.P$2, J50.4
GAIN25: IC26.P$2, J52.4
GAIN26: IC27.P$2, J54.4
GAIN27: IC28.P$2, J56.4
GAIN28: IC29.P$2, J58.4
GAIN29: IC30.P$2, J60.4
GAIN30: IC31.P$2, J62.4
GAIN31: IC32.P$2, J64.4
GAIN32: IC33.P$2, J66.4
GAIN33: IC34.P$2, J68.4
GAIN34: IC35.P$2, J70.4
GAIN35: IC36.P$2, J72.4
GAIN36: IC37.P$2, J74.4
GAIN37: IC38.P$2, J76.4
GAIN38: IC39.P$2, J78.4
GAIN39: IC40.P$2, J80.4
GAIN40: IC41.P$2, J82.4
GAIN41: IC42.P$2, J84.4
GAIN42: IC43.P$2, J86.4
GAIN43: IC44.P$2, J88.4
GAIN44: IC45.P$2, J90.4
GAIN45: IC46.P$2, J92.4
GAIN46: IC47.P$2, J94.4
GAIN47: IC48.P$2, J96.4
GAIN48: IC49.P$2, J98.4
GAIN49: IC50.P$2, J100.4
GAIN50: IC51.P$2, J102.4
GAIN51: IC52.P$2, J104.4
GAIN52: IC53.P$2, J106.4
GAIN53: IC54.P$2, J108.4
GAIN54: IC55.P$2, J110.4
GAIN55: IC56.P$2, J112.4
GAIN56: IC57.P$2, J114.4
GAIN57: IC58.P$2, J116.4
GAIN58: IC59.P$2, J118.4
GAIN59: IC60.P$2, J120.4
GAIN60: IC61.P$2, J122.4
GAIN61: IC62.P$2, J124.4
GAIN62: IC63.P$2, J126.4
GAIN63: IC64.P$2, J128.4
GAIN64: IC65.P$2, J130.4
GAIN65: IC66.P$2, J132.4
GAIN66: IC67.P$2, J134.4
GAIN67: IC68.P$2, J136.4
GAIN68: IC69.P$2, J138.4
GAIN69: IC70.P$2, J140.4
GND: C1.2, C2.2, IC1.P$3, IC1.P$11, IC1.P$15, IC1.P$EP, J2.6
GND1: C3.2, C4.2, IC2.P$3, IC2.P$11, IC2.P$15, IC2.P$EP, J4.6
GND2: C5.2, C6.2, IC3.P$3, IC3.P$11, IC3.P$15, IC3.P$EP, J6.6
GND3: C7.2, C8.2, IC4.P$3, IC4.P$11, IC4.P$15, IC4.P$EP, J8.6
GND4: C9.2, C10.2, IC5.P$3, IC5.P$11, IC5.P$15, IC5.P$EP, J10.6
GND5: C11.2, C12.2, IC6.P$3, IC6.P$11, IC6.P$15, IC6.P$EP, J12.6
GND6: C13.2, C14.2, IC7.P$3, IC7.P$11, IC7.P$15, IC7.P$EP, J14.6
GND7: C15.2, C16.2, IC8.P$3, IC8.P$11, IC8.P$15, IC8.P$EP, J16.6
GND8: C17.2, C18.2, IC9.P$3, IC9.P$11, IC9.P$15, IC9.P$EP, J18.6
GND9: C19.2, C20.2, IC10.P$3, IC10.P$11, IC10.P$15, IC10.P$EP, J20.6
GND10: C21.2, C22.2, IC11.P$3, IC11.P$11, IC11.P$15, IC11.P$EP, J22.6
GND11: C23.2, C24.2, IC12.P$3, IC12.P$11, IC12.P$15, IC12.P$EP, J24.6
GND12: C25.2, C26.2, IC13.P$3, IC13.P$11, IC13.P$15, IC13.P$EP, J26.6
GND13: C27.2, C28.2, IC14.P$3, IC14.P$11, IC14.P$15, IC14.P$EP, J28.6
GND14: C29.2, C30.2, IC15.P$3, IC15.P$11, IC15.P$15, IC15.P$EP, J30.6
GND15: C31.2, C32.2, IC16.P$3, IC16.P$11, IC16.P$15, IC16.P$EP, J32.6
GND16: C33.2, C34.2, IC17.P$3, IC17.P$11, IC17.P$15, IC17.P$EP, J34.6
GND17: C35.2, C36.2, IC18.P$3, IC18.P$11, IC18.P$15, IC18.P$EP, J36.6
GND18: C37.2, C38.2, IC19.P$3, IC19.P$11, IC19.P$15, IC19.P$EP, J38.6
GND19: C39.2, C40.2, IC20.P$3, IC20.P$11, IC20.P$15, IC20.P$EP, J40.6
GND20: C41.2, C42.2, IC21.P$3, IC21.P$11, IC21.P$15, IC21.P$EP, J42.6
GND21: C43.2, C44.2, IC22.P$3, IC22.P$11, IC22.P$15, IC22.P$EP, J44.6
GND22: C45.2, C46.2, IC23.P$3, IC23.P$11, IC23.P$15, IC23.P$EP, J46.6
GND23: C47.2, C48.2, IC24.P$3, IC24.P$11, IC24.P$15, IC24.P$EP, J48.6
GND24: C49.2, C50.2, IC25.P$3, IC25.P$11, IC25.P$15, IC25.P$EP, J50.6
GND25: C51.2, C52.2, IC26.P$3, IC26.P$11, IC26.P$15, IC26.P$EP, J52.6
GND26: C53.2, C54.2, IC27.P$3, IC27.P$11, IC27.P$15, IC27.P$EP, J54.6
GND27: C55.2, C56.2, IC28.P$3, IC28.P$11, IC28.P$15, IC28.P$EP, J56.6
GND28: C57.2, C58.2, IC29.P$3, IC29.P$11, IC29.P$15, IC29.P$EP, J58.6
GND29: C59.2, C60.2, IC30.P$3, IC30.P$11, IC30.P$15, IC30.P$EP, J60.6
GND30: C61.2, C62.2, IC31.P$3, IC31.P$11, IC31.P$15, IC31.P$EP, J62.6
GND31: C63.2, C64.2, IC32.P$3, IC32.P$11, IC32.P$15, IC32.P$EP, J64.6
GND32: C65.2, C66.2, IC33.P$3, IC33.P$11, IC33.P$15, IC33.P$EP, J66.6
GND33: C67.2, C68.2, IC34.P$3, IC34.P$11, IC34.P$15, IC34.P$EP, J68.6
GND34: C69.2, C70.2, IC35.P$3, IC35.P$11, IC35.P$15, IC35.P$EP, J70.6
GND35: C71.2, C72.2, IC36.P$3, IC36.P$11, IC36.P$15, IC36.P$EP, J72.6
GND36: C73.2, C74.2, IC37.P$3, IC37.P$11, IC37.P$15, IC37.P$EP, J74.6
GND37: C75.2, C76.2, IC38.P$3, IC38.P$11, IC38.P$15, IC38.P$EP, J76.6
GND38: C77.2, C78.2, IC39.P$3, IC39.P$11, IC39.P$15, IC39.P$EP, J78.6
GND39: C79.2, C80.2, IC40.P$3, IC40.P$11, IC40.P$15, IC40.P$EP, J80.6
GND40: C81.2, C82.2, IC41.P$3, IC41.P$11, IC41.P$15, IC41.P$EP, J82.6
GND41: C83.2, C84.2, IC42.P$3, IC42.P$11, IC42.P$15, IC42.P$EP, J84.6
GND42: C85.2, C86.2, IC43.P$3, IC43.P$11, IC43.P$15, IC43.P$EP, J86.6
GND43: C87.2, C88.2, IC44.P$3, IC44.P$11, IC44.P$15, IC44.P$EP, J88.6
GND44: C89.2, C90.2, IC45.P$3, IC45.P$11, IC45.P$15, IC45.P$EP, J90.6
GND45: C91.2, C92.2, IC46.P$3, IC46.P$11, IC46.P$15, IC46.P$EP, J92.6
GND46: C93.2, C94.2, IC47.P$3, IC47.P$11, IC47.P$15, IC47.P$EP, J94.6
GND47: C95.2, C96.2, IC48.P$3, IC48.P$11, IC48.P$15, IC48.P$EP, J96.6
GND48: C97.2, C98.2, IC49.P$3, IC49.P$11, IC49.P$15, IC49.P$EP, J98.6
GND49: C99.2, C100.2, IC50.P$3, IC50.P$11, IC50.P$15, IC50.P$EP, J100.6
GND50: C101.2, C102.2, IC51.P$3, IC51.P$11, IC51.P$15, IC51.P$EP, J102.6
GND51: C103.2, C104.2, IC52.P$3, IC52.P$11, IC52.P$15, IC52.P$EP, J104.6
GND52: C105.2, C106.2, IC53.P$3, IC53.P$11, IC53.P$15, IC53.P$EP, J106.6
GND53: C107.2, C108.2, IC54.P$3, IC54.P$11, IC54.P$15, IC54.P$EP, J108.6
GND54: C109.2, C110.2, IC55.P$3, IC55.P$11, IC55.P$15, IC55.P$EP, J110.6
GND55: C111.2, C112.2, IC56.P$3, IC56.P$11, IC56.P$15, IC56.P$EP, J112.6
GND56: C113.2, C114.2, IC57.P$3, IC57.P$11, IC57.P$15, IC57.P$EP, J114.6
GND57: C115.2, C116.2, IC58.P$3, IC58.P$11, IC58.P$15, IC58.P$EP, J116.6
GND58: C117.2, C118.2, IC59.P$3, IC59.P$11, IC59.P$15, IC59.P$EP, J118.6
GND59: C119.2, C120.2, IC60.P$3, IC60.P$11, IC60.P$15, IC60.P$EP, J120.6
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

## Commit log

2018-06-21 Initial Commit
    Added schematic and board files
    [SparkFun_I2S_Audio_Breakout.brd, SparkFun_I2S_Audio_Breakout.sch]
2018-06-22 Design review changes
    Moved buzzard labels away from headers slightly
    [SparkFun_I2S_Audio_Breakout.brd]
2018-06-25 Updated Bottom Silk
    Used new buzzard labels so the bottom of the board is more readable within Eagle.
    [SparkFun_I2S_Audio_Breakout.brd]
2018-07-17 v10
    Removed + symbol on top copper
    Removed ferrite beads
    [SparkFun_I2S_Audio_Breakout.brd, SparkFun_I2S_Audio_Breakout.sch]
2018-07-20 v10 panel
    [SparkFun_I2S_Audio_Breakout-Panel.brd, SparkFun_I2S_Audio_Breakout.brd]
2018-08-29 Fixed IC1 Value
    -Fixed IC1 value from MAX98375A to MAX98357A
    [SparkFun_I2S_Audio_Breakout.brd, SparkFun_I2S_Audio_Breakout.sch]
2018-09-05 Repo Cleanup
    - Moved board files into /Hardware folder
    - Updated readme
    [SparkFun_I2S_Audio_Breakout.brd, SparkFun_I2S_Audio_Breakout.sch]

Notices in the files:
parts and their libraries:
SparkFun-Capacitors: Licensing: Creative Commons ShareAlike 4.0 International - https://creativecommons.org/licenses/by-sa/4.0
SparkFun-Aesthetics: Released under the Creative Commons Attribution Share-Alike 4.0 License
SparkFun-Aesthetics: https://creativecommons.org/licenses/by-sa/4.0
